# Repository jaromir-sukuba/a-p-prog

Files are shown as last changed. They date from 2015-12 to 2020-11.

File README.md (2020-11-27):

# Programmer for 8-bit PIC devices built upon AVR (or Arduino)

For [Micro progmeter](https://github.com/jaromir-sukuba/micro_progmeter) project I want to deliver full set of open-source materials, but it would be shame if folks trying to replicate the project would have to buy another programmer to flash the PIC MCU, so I decided to do a little bit of brain stretching and implement PIC16F1xxx programmer with... Arduino. I really can't say I love this platform, but it is low cost and available.
Together with SDCC compiler this serves as completely open-source basis for many 8-bit PIC devices.

The current project status: Programmer working, sources need cleanup, perhaps rework of its structure (it grew out of its simple structure).
# List of supported devices is at the end of this page.

## Hardware
There are two options fo hardware for this project:

### Hardware option 1 - Arduino hardware
Take any Arduino with ATmega328P, like Uno or most of cheap chinese knock-off boards. Considering the target has its own power supply, connect GND, MCLR, PGC and PGD lines to respective pins on arduino as follows:

| Arduino pin | AVR pin | Target PIC pin | Comment |
|---|---|---|---|
| GND | GND | GND | common ground |
| 5V | VDD | VDD | optional*- power supply for PIC MCU, you may power target from other source |
| A3 | PC3 | MCLR | reset line of PIC MCU |
| A1 | PC1 | PGD | programming data line |
| A0 | PC0 | PGC | programming clock line |

* If you are powering target PIC from other power source (in circuit programming), series resistors (something like 470-1000 Ohms) in MCLR, PGC and PGD lines are good idea, it will somehow decrease currents flowing through IO pins due to power supplies differences between arduino and target board. In this configuration, even targets running at 3,3V are possible to program, though it is dirty practice.

Power it up, no smoke should be released. Run arduino IDE, open programmer firmware from here (/fw/pp.ino), complie and upload to arduino board - now you have PIC programmer ready to go. Go to software below.

The programmer is proven to work with some generic Uno board from china, as well as chinese arduino-nano clone


### Hardware option 2 - dedicated board
I designed this little board, see at /hw directory

Considering the target has its own power supply, connect GND, MCLR, PGC and PGD lines to respective pins on PIC programmer (notice the pinout similar to PICkit programmers). Vdd line is not currently used ad it is not needed for operation of programmer, but future revisions of firmware may take advantage of this pin and detect target VDD.
The hardware works with both FT232RL and CY7C65213 in place of USB/serial converter. Both were proven to work, with no other hardware difference.


Use [another arduino](https://www.arduino.cc/en/Tutorial/ArduinoISP) (or proper ISP programmer) to load Arduino UNO bootloader to PIC programmer board (performed only once), turning it into regular arduino compatible board.



Ensure JP2 is closed, then you can load new firmware into PIC programmer using regular Arduino IDE. Open jumper JP2. Now you have your programmer ready to go, move on to software.
The firmware should be able to compile outside Arduino IDE as it doesn't contain any Arduino-specific stuff, though I haven't tried that.

## Software

When running under Linux, download source from this repository and run

`gcc -Wall pp3.c -o pp3`

This should build executable pp3. When working under windows, you can download compiled binary from this repository. Alternatively, you can build it from source - install minGW and run

`gcc -Wall pp3.c -o pp3`

ie. the same procedure as on Linux. This should result in silent build with pp3.exe executable created.

Running the executable with no parameters should only bring banner "pp programmer". Though running with basic set of parameters

`./pp3 -c /dev/ttyACM0 -t 16f1829 file.hex`

under Linux, where -c parameter denotes port to be accessed, -t parameter defines PIC to be programmed and last parameter is hex file to be downloaded; or

`pp3.exe -c COM30 -t 16f1829 file.hex`

under Windows should program the target PIC; with expected result:

	$ ./pp3 -c /dev/ttyACM0 -t 16f1829 file.hex
    Opening serial port
    Device ID 0x27E4
    Programming FLASH (16384 B in 256 pages)
    Programming config
    Verifying FLASH (16384 B in 256 pages)
    Verifying config
    Releasing MCLR

## Notes on software

If you are running the hardware on generic arduino board or you forget to open jumper JP2 after loading firmware on dedicated hardware, you may need to insert waiting time after opening serial port and before communication - to ensure Arduino bootloader times out after opening serial port and takes control to programmer firmware. It should look like this

`pp3.exe -c COM30 -s 1700 -t 16f1829 file.bin`

where number after -s switch defines the number of miliseconds to wait after opening the serial port.

You may omit the actual programming using -p switch or verification using -n switch, when using both the programmer only checks target device signature and exits.

`$ ./pp3 -c /dev/ttyACM0 -p -n -t 16f1829 file.bin`

    Opening serial port
    Device ID 0x27E4
    Releasing MCLR

you can add some debug output info using -v parameter, ranging from -v 1 to -v 4. It may be suitable for debugging, -v 4 prints out all byte transaction on serial port, so be prepared for huge output.
There is database file pp3_devices.dat which hold information of supported PIC types. For now, the filename is fixed in code can't be changed and file has to be in the same directory as pp executable..

## Supported devices

Obviously, there is more supported than verified (tested) devices. I tried to test at least one device from specific family. The members from one family are usually very very similar, giving me enough confidence to mark them as supproted. Of course, typos can happen, but those are easy to correct.

**DEVICE**|**TESTED**
:-----:|:-----:
PIC12F1501|YES
PIC12F1571| 
PIC12F1572|YES
PIC12F1612|YES
PIC12F1822|YES
PIC12F1840|YES
PIC12LF1501|YES
PIC12LF1552|YES
PIC12LF1571| 
PIC12LF1572| 
PIC12LF1612| 
PIC12LF1822| 
PIC12LF1840|YES
PIC16F1454| 
PIC16F1455|YES
PIC16F1459| 
PIC16F1503|YES
PIC16F1507|YES
PIC16F1508| 
PIC16F1509|YES
PIC16F1512| 
PIC16F1513| 
PIC16F1516|YES
PIC16F1517| 
PIC16F1518| 
PIC16F1519| 
PIC16F1528| 
PIC16F1529| 
PIC16F15313| 
PIC16F15323| 
PIC16F15324| 
PIC16F15325| 
PIC16F15344| 
PIC16F15345| 
PIC16F15354| 
PIC16F15355|YES
PIC16F15356| 
PIC16F15375| 
PIC16F15376| 
PIC16F15385| 
PIC16F15386| 
PIC16F1574| 
PIC16F1575|YES
PIC16F1578| 
PIC16F1579| 
PIC16F1613|YES
PIC16F1614| 
PIC16F1615|YES
PIC16F1618| 
PIC16F1619|YES
PIC16F1703|YES
PIC16F1704| 
PIC16F1705| 
PIC16F1707| 
PIC16F1708| 
PIC16F1709| 
PIC16F1713| 
PIC16F1716| 
PIC16F1717| 
PIC16F1718|YES
PIC16F1719| 
PIC16F1764| 
PIC16F1765|YES
PIC16F1768| 
PIC16F1769| 
PIC16F1782| 
PIC16F1783|YES
PIC16F1784| 
PIC16F1786| 
PIC16F1787| 
PIC16F1788|YES
PIC16F1789| 
PIC16F1824| 
PIC16F1825| 
PIC16F1826| 
PIC16F1827| 
PIC16F1828| 
PIC16F1829|YES
PIC16F18313| 
PIC16F18323| 
PIC16F18324| 
PIC16F18325| 
PIC16F18326| 
PIC16F18344| 
PIC16F18345| 
PIC16F18346|YES
PIC16F18424| 
PIC16F18425| 
PIC16F18426| 
PIC16F18444| 
PIC16F18445| 
PIC16F18446| 
PIC16F18455| 
PIC16F18456| 
PIC16F1847| 
PIC16F18854| 
PIC16F18855|YES
PIC16F18856| 
PIC16F18857| 
PIC16F18875|YES
PIC16F18876| 
PIC16F18877| 
PIC16F19155| 
PIC16F19156|YES
PIC16F19175| 
PIC16F19176|YES
PIC16F19185| 
PIC16F19186| 
PIC16F19195| 
PIC16F19196| 
PIC16F19197| 
PIC16F1933|YES
PIC16F1934| 
PIC16F1936| 
PIC16F1937| 
PIC16F1938| 
PIC16F1939| 
PIC16F1946| 
PIC16F1947| 
PIC16LF1454| 
PIC16LF1455|YES
PIC16LF1459| 
PIC16LF1503|YES
PIC16LF1507| 
PIC16LF1508|YES
PIC16LF1509| 
PIC16LF1512| 
PIC16LF1513| 
PIC16LF1516| 
PIC16LF1517| 
PIC16LF1518| 
PIC16LF1519| 
PIC16LF1528| 
PIC16LF1529| 
PIC16LF15313| 
PIC16LF15323| 
PIC16LF15324| 
PIC16LF15325| 
PIC16LF15344| 
PIC16LF15345| 
PIC16LF15354| 
PIC16LF15355| 
PIC16LF15356| 
PIC16LF15375| 
PIC16LF15376| 
PIC16LF15385| 
PIC16LF15386| 
PIC16LF1574| 
PIC16LF1575| 
PIC16LF1578| 
PIC16LF1579| 
PIC16LF1613| 
PIC16LF1614| 
PIC16LF1615| 
PIC16LF1618| 
PIC16LF1619|
PIC16LF1703| 
PIC16LF1704|YES
PIC16LF1705| 
PIC16LF1707| 
PIC16LF1708| 
PIC16LF1709| 
PIC16LF1713|YES
PIC16LF1716| 
PIC16LF1717| 
PIC16LF1718| 
PIC16LF1719| 
PIC16LF1764| 
PIC16LF1765| 
PIC16LF1768| 
PIC16LF1769| 
PIC16LF1782| 
PIC16LF1783| 
PIC16LF1784| 
PIC16LF1786| 
PIC16LF1787| 
PIC16LF1788| 
PIC16LF1789| 
PIC16LF1824| 
PIC16LF1825| 
PIC16LF1826| 
PIC16LF1827| 
PIC16LF1828| 
PIC16LF1829|YES
PIC16LF18313| 
PIC16LF18323| 
PIC16LF18324| 
PIC16LF18325| 
PIC16LF18326| 
PIC16LF18344| 
PIC16LF18345| 
PIC16LF18346| 
PIC16LF18424| 
PIC16LF18425| 
PIC16LF18444| 
PIC16LF18445| 
PIC16LF18455| 
PIC16LF18456| 
PIC16LF1847| 
PIC16LF18854| 
PIC16LF18855| 
PIC16LF18856| 
PIC16LF18857| 
PIC16LF18875| 
PIC16LF18876| 
PIC16LF18877| 
PIC16LF1902| 
PIC16LF1903|YES
PIC16LF1904| 
PIC16LF1906| 
PIC16LF1907| 
PIC16LF19155| 
PIC16LF19156| 
PIC16LF19175| 
PIC16LF19176| 
PIC16LF19185| 
PIC16LF19186| 
PIC16LF19195| 
PIC16LF19196| 
PIC16LF19197| 
PIC16LF1933| 
PIC16LF1934| 
PIC16LF1936| 
PIC16LF1937| 
PIC16LF1938| 
PIC16LF1939| 
PIC16LF1946| 
PIC16LF1947| 
PIC18F23K22| 
PIC18F24J10|YES
PIC18F24J11| 
PIC18F24J50|YES
PIC18F24K22|YES
PIC18F24K40| 
PIC18F24K42| 
PIC18F24K50| 
PIC18F25J10| 
PIC18F25J11| 
PIC18F25J50| 
PIC18F25K22| 
PIC18F25K40| 
PIC18F25K42| 
PIC18F25K50|YES
PIC18F25K80|YES
PIC18F25Q10|YES
PIC18F26J11|YES
PIC18F26J13| 
PIC18F26J50|YES
PIC18F26J53| 
PIC18F26K22|YES
PIC18F26K40| 
PIC18F26K42| 
PIC18F26K50| 
PIC18F26K80| 
PIC18F26Q10| 
PIC18F27J13| 
PIC18F27J53|YES
PIC18F27K40| 
PIC18F27K42| 
PIC18F27Q10| 
PIC18F43K22| 
PIC18F44J10| 
PIC18F44J11| 
PIC18F44J50| 
PIC18F44K22| 
PIC18F45J10|YES
PIC18F45J11| 
PIC18F45J50| 
PIC18F45K22| 
PIC18F45K40| 
PIC18F45K42| 
PIC18F45K50| 
PIC18F45K80| 
PIC18F45Q10| 
PIC18F46J11| 
PIC18F46J13| 
PIC18F46J50| 
PIC18F46J53| 
PIC18F46K22| 
PIC18F46K40| 
PIC18F46K42| 
PIC18F46K50| 
PIC18F46K80| 
PIC18F46Q10| 
PIC18F47J13| 
PIC18F47J53| 
PIC18F47K40|YES
PIC18F47K42| 
PIC18F47Q10| 
PIC18F55K42| 
PIC18F56K42| 
PIC18F57K42|YES
PIC18F63J11| 
PIC18F63J90| 
PIC18F64J11| 
PIC18F64J90| 
PIC18F65J10| 
PIC18F65J11| 
PIC18F65J15| 
PIC18F65J50| 
PIC18F65J90| 
PIC18F65J94| 
PIC18F65K22| 
PIC18F65K40| 
PIC18F65K80| 
PIC18F65K90| 
PIC18F66J10| 
PIC18F66J11| 
PIC18F66J15|YES
PIC18F66J16| 
PIC18F66J50| 
PIC18F66J55| 
PIC18F66J60| 
PIC18F66J65| 
PIC18F66J90| 
PIC18F66J93| 
PIC18F66J94| 
PIC18F66J99| 
PIC18F66K22| 
PIC18F66K40| 
PIC18F66K80| 
PIC18F66K90| 
PIC18F67J10| 
PIC18F67J11| 
PIC18F67J50|YES
PIC18F67J60| 
PIC18F67J90| 
PIC18F67J93| 
PIC18F67J94| 
PIC18F67K22|YES
PIC18F67K40| 
PIC18F67K90| 
PIC18F83J11| 
PIC18F83J90| 
PIC18F84J11| 
PIC18F84J90| 
PIC18F85J10| 
PIC18F85J11| 
PIC18F85J15| 
PIC18F85J50| 
PIC18F85J90| 
PIC18F85J94| 
PIC18F85K22| 
PIC18F85K90| 
PIC18F86J10| 
PIC18F86J11| 
PIC18F86J15| 
PIC18F86J16| 
PIC18F86J50| 
PIC18F86J55| 
PIC18F86J60| 
PIC18F86J65| 
PIC18F86J72| 
PIC18F86J90| 
PIC18F86J93| 
PIC18F86J94| 
PIC18F86J99| 
PIC18F86K22| 
PIC18F86K90| 
PIC18F87J10| 
PIC18F87J11| 
PIC18F87J50| 
PIC18F87J60| 
PIC18F87J72| 
PIC18F87J90| 
PIC18F87J93| 
PIC18F87J94| 
PIC18F87K22| 
PIC18F87K90| 
PIC18F95J94| 
PIC18F96J60| 
PIC18F96J65| 
PIC18F96J94| 
PIC18F96J99| 
PIC18F97J60| 
PIC18F97J94| 
PIC18LF23K22| 
PIC18LF24J10| 
PIC18LF24J11| 
PIC18LF24J50| 
PIC18LF24K22| 
PIC18LF24K40| 
PIC18LF24K42| 
PIC18LF24K50|YES
PIC18LF25J10| 
PIC18LF25J11| 
PIC18LF25J50| 
PIC18LF25K22|YES
PIC18LF25K40| 
PIC18LF25K42| 
PIC18LF25K50|YES
PIC18LF25K80| 
PIC18LF26J11| 
PIC18LF26J13| 
PIC18LF26J50| 
PIC18LF26J53| 
PIC18LF26K22| 
PIC18LF26K40| 
PIC18LF26K42| 
PIC18LF26K50| 
PIC18LF26K80| 
PIC18LF27J13| 
PIC18LF27J53| 
PIC18LF27K40| 
PIC18LF27K42| 
PIC18LF43K22| 
PIC18LF44J10| 
PIC18LF44J11| 
PIC18LF44J50| 
PIC18LF44K22| 
PIC18LF45J10| 
PIC18LF45J11| 
PIC18LF45J50| 
PIC18LF45K22| 
PIC18LF45K40| 
PIC18LF45K42| 
PIC18LF45K50| 
PIC18LF45K80| 
PIC18LF46J11| 
PIC18LF46J13| 
PIC18LF46J50| 
PIC18LF46J53| 
PIC18LF46K22| 
PIC18LF46K40| 
PIC18LF46K42| 
PIC18LF46K50| 
PIC18LF46K80| 
PIC18LF47J13| 
PIC18LF47J53| 
PIC18LF47K40| 
PIC18LF47K42| 
PIC18LF55K42| 
PIC18LF56K42| 
PIC18LF57K42| 
PIC18LF65K40| 
PIC18LF65K80| 
PIC18LF66K40| 
PIC18LF66K80| 
PIC18LF67K40| 

The whole project is licensed under MIT license, see LICENSE.md file.
Some more details to be found here https://hackaday.io/project/8559-pic16f1xxx-arduino-based-programmer

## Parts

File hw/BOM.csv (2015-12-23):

Qty | Value | Device | Package | Parts | Description | PROD_ID | VALUE
1 |  | JP1E | JP1 | JP2 | JUMPER
2 |  | LEDCHIPLED_0805 | CHIPLED_0805 | LED1; LED2 | LED
1 |  | PINHD-1X5/90 | 1X05/90 | JP1 | PIN HEADER
2 | 10k | R_0805 | R0805 | R3; R6
1 | 16MHz | CRYSTALHC49S | HC49/S | Q1 | CRYSTAL
4 | 1u | C_0806 | R0805 | C1; C2; C3; C4
2 | 22p | C_0806 | R0805 | C5; C6
6 | 470 | R_0805 | R0805 | R1; R2; R4; R5; R7; R8
1 | ATMEGA328P | ATMEGA328_SMT | TQFP32-08 | U1 | 32-Pin Atmega328 part | IC-09069 | ATMEGA328P
1 | AVR_SPI_PRG_6NS | AVR_SPI_PRG_6NS | 2X3-NS | J | AVR ISP 6 Pin
1 | FT232RL | FT232RLSSOP | SSOP28DB | IC1 | USB UART
1 | USB-MICROB | USB-MICROB | USB-MICROB | X1 | USB Connectors

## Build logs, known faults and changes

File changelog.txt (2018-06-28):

2015-12-23
- version 0.0
- PIC16F1829, PIC16F1825, PIC16LF1829 and PIC16LF1825 supported

2016-01-18
- version 0.0
- 16F1507, 1508 and LF variants added

2016-04-01
- version 0.0
- 18F25K50 added
- hex file support

2016-07-26
- version 0.0
- PIC18 bugs fixed
- 12F1571, 1572 and its LF variants added

2016-07-29
- version 0.0
- a lot of devices added and tested, 42 devices in total supported

2016-07-30
- version 0.0
- PIC12F18xx fixed
- a fex PIC16F devices tested

2016-08-05
- version 0.0
- PIC16F1619 and 1579 families added
- 68 devices supported

2016-08-16
- version 0.0
- 16F151x, 16F178x, 16F19xx families added
- PIC18FxxJxx family added
- 131 devices supported

2016-09-05
- version 0.9 (finally some sensible release number, 1.0 release is near)
- a lot of PIC18FxxJxx devices added
- bugfixes around serial port, hex file parsing and PIC18FxxKxx support
- PIC type in command line is now case insensitive
- 175 devices supported

2016-09-06
- version 0.91 (previous should be 0.90, then)
- improved programming speed, especially at windows (improved serial port handling)
- some more intelligence in PIC16 programming, results in faster programming
- PIC16F17xx devices added, 205 devices supported now

2016-09-07
- version 0.92
- major rewrite of MCU selection routines: instead of hardcoded if-then behemoth, 
there is external database parser, all MCU parameter are here in plain text
- source code shrinked from 2700 lines to 900
- source code slightly cleaned up and formatted
- added 67 new devices from PIC18FxxJxx family and one PIC16, resulting in 273 total

2016-09-12
- version 0.93
- fixed bugs for some older 18FxxJxx devices
- more devices tested

2016-09-14
- version 0.94
- added support for 12 new devices from PIC18FxxK80 family, 285 in total
- PIC18F25K80 tested
- some bugfixes

2016-09-16
- version 0.95
- added support for some PIC18FxxK22 and PIC18FxxK50 devcies, 305 in total
- there is not much LVP ICSP-able 8-bit PIC devcies left
- some more devices tested, 47 in total

2018-06-17
- after a long hiatus, version 0.96
- implemented newly introduced programming algorithm for PIC16F1xxxx devices
- hopefully nothing old broken
- 14 new devices, resulting in 319 total
- some new devcies still missing

2018-06-18
- vresion 0.97
- some PIC16F devices are somehow faster to program
- new devices added PIC16F183xx, PIC16F185xx, PIC16F19xxx), 379 in total

2018-06-19
- version 0.98
- PIC16F184xx, PIC18FxxK40 and PIC18Fxx42 added, now 433 devices in total
- minor programming speed increase

2018-06-28
- version 0.99
- PIC18FxxQ10 support added, now 439 devices in total

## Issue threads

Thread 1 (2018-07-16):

Need help to use this to update PIC18F57K42

ashasingh2018, 2018-07-16:
Hi,
My system consists of a 4Duino (has ATmega32U4, AVR) and PIC18F57K42.  The
4Duino talks to the PIC via I2C.
The 4Duino has a USB interface that can talk to the PC

I use Arduino IDE to build the 4Duino code and flash the 4Duino.
I use a JTAG programmer to flash the PIC code (uses ICD 3 and MPLAB v4.15). But to do this we have to open the encasing to get to the JTAG pins which is why we want to be able to do the PIC firmware upgrade without opening the encasing.

I looked at your programming tool here and I was wondering if I would be able to use it.
Can I use the 4Duino with your pp.ino to program the pic ?

I tried to build pp.ino using the IDE but it failed because of the macros  below -- it cannot find these.
     UBRR0H = ((_UBRR) & 0xF00);
    UBRR0L = (uint8_t) ((_UBRR) & 0xFF);
     UCSR0B |= _BV(TXEN0);
     UCSR0B |= _BV(RXEN0);

Any help and suggestion would be appreciated very much. Thanks, Asha

jaromir-sukuba, 2019-01-11:
The firmware is using Atmega328 specific IO access. It can be probably ported to USB based devices, but it will not be trivial and I'm not planning to do this in near future.
For now I'm closing this issue.

Closed 2019-01-11.

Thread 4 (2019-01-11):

Config errors?

martiinezz, 2019-01-11:
PP programmer, version 0.99
Sleeping for 1700 ms while arduino bootloader expires
Device ID: 2760
Programming FLASH (16384 B in 256 pages)
Programming config
Verifying FLASH (16384 B in 256 pages)
Verifying config
config 2 error: E:0x3EFF R:0x1EFF

Can you tell me why I do get this errors? It seems like PIC is not being programmed correctly. Works but not in full. Any ideas how to fix this?

jaromir-sukuba, 2019-01-11:
Could you, please share the hex file you are programming and command line you are using to run the programmer software, so I can reproduce the error?

martiinezz, 2019-01-11:
Doing this on Linux (Mint 18.3) with command:
pp3 -c /dev/ttyUSB0 -s 1700 -t 16f1825 simple-basic.hex

[hex.zip](https://github.com/jaromir-sukuba/a-p-prog/files/2749771/hex.zip)

Both files give the same errors.

The source code comes from here:

https://github.com/kortas87/simple-evse/tree/master/simple-evse.X

martiinezz, 2019-01-18:
Any hints what's wrong?

martiinezz, 2019-02-01:
Compilation summary:

Memory Summary:
    Program space        used   39Bh (   923) of  2000h words   ( 11.3%)
    Data space           used    38h (    56) of   400h bytes   (  5.5%)
    EEPROM space         used     0h (     0) of   100h bytes   (  0.0%)
    Data stack space     used     0h (     0) of   3C8h bytes   (  0.0%)
    Configuration bits   used     2h (     2) of     2h words   (100.0%)
    ID Location space    used     0h (     0) of     4h bytes   (  0.0%)

I think the problem is with Configuration bits - everything else seems to work just fine.

delight-f, 2021-09-30:
Same error for me!!

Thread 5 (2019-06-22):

Programming PIC18F14K50

matangk, 2019-06-22:
Great work so far!
Any reason it wont work with PIC18F14K50?
Its not on the supported device list..
Cheers!

jaromir-sukuba, 2020-11-27:
This one requires either high voltage on MCLR or wiggling with PGM pin, that is older variant of low voltage programming.
I decided to support only newer low voltage programming PIC types (starting ~ 10 years ago), so 14K50 will not be supported any time soon.

Closed 2020-11-27.

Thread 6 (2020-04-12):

How can I figure out theMK preferences?

vporoshok, 2020-04-12:
Hi! I have a circuit based on PIC16F84A. I've tried this project to upload the hex file on it, but there is no this MK in the database. I've found flash size from data sheets, but how can I get other options: page size, id, and mask?

jaromir-sukuba, 2020-04-12:
PIC16F84A can't be programmed using the hardware, as PIC16F84A doesn't support low voltage programming (LVP) and therefore isn't supported in software too.

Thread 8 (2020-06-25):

PIC24FJ

fabioriksilva, 2020-06-25:
Is it possible make some changes in this project to add 24FJ(16bit) processors?
  Today, I'm using ARM in 90% of my projects, cause of that I have made a pattern writer in all my projects using the DAPlink project as: https://github.com/ARMmbed/DAPLink.

   This project has an usart CDC implemented, that runs very well.

    So, I would like tho know if you can helping me to put up the model:
    PIC24FJ128GC010
    https://www.microchip.com/wwwproducts/en/PIC24FJ128GC010

    I really would appreciate your help, as I just starting with github projects.

   Thank you so much!

jaromir-sukuba, 2020-06-26:
Hello,
from technical point of view, there is nothing stopping from adding 16-bit MCU support and at some point in the project I thought of adding it, however I decided no to do it, because:
1, Programmer is slow (theoretical limit is 5kB/s, however it's less in practice due to simple buffering). 8-bitters do usually have less of FLASH than 16-bit ones, so this slow-ness isn't that much of a problem.
2, There isn't open source compiler for 16-bit PICs. This simple open-source programmer is good match to SDCC.
Users using XC16 can also use rest of Microchip's ecosystem with their programmers, being MUCH faster than this arduino based one.
3, It's quite bit of work and adding it into my spaghetti code wouldn't be pleasing experience.

The programmer software and firmware would need at least major rewrite in order to become half-usable 16-bit PIC programmer. Ideally, hardware rework would be advisable, because this started as one-off quick project and grown much out of original scope.
So, for now the answer is no, but I'm open to pull requests.

Closed 2020-07-02.

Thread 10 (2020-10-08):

facing problem while flashing PIC16F18875

embhobbb, 2020-10-08:
i am using your programmer to flash PIC16F18875 but i am getting error as follows.
```
E:\DIY\Programmer\PIC Programmer using Arduino\picProg\sw>pp3.exe -c COM4 -s 1700 -t 16f18875 PwmGen.X.production.hex
PP programmer, version 0.99
Sleeping for 1700 ms while arduino bootloader expires
Wrong device ID: 0000, expected: 306d
Check for connection to target MCU, exiting now
```

I could able to flash other controller PIC16F1847 but not this one.
PIC16F18875 has MCLR resistor of 10K connected and pulled up to VDD. other than this i have not connected anything.

embhobbb, 2020-10-08:
```
pp3.exe -c COM4 -s 1700 -t 16f18875 PwmGen.X.production.hex
PP programmer, version 0.99
Sleeping for 1700 ms while arduino bootloader expires
Wrong device ID: 0000, expected: 306d
Check for connection to target MCU, exiting now
```

jaromir-sukuba, 2020-11-27:
This looks like a duplicate of issue #9 , closing.

embhobbb, 2020-12-01:
Thanks for your reply. My connection is very simple which works with pickit3. But my pickit3 is not working now. I found your project very helpful. Here are the commands i was trying..
E:\DIY\Programmer\PIC Programmer using Arduino\picProg\sw>pp3.exe -c COM12  -s 1700 -t 16f18875 test.X.production.hex
PP programmer, version 0.99
Sleeping for 1700 ms while arduino bootloader expires
Device ID: 306d
Programming FLASH (16384 B in 256 pages)
Programming config
Verifying FLASH (16384 B in 256 pages)
Verifying config
Error at 0x4007 E:0x1F R:0x3F

embhobbb, 2020-12-01:
[test.X.production.txt](https://github.com/jaromir-sukuba/a-p-prog/files/5622251/test.X.production.txt)

here is the attached hex file. Please change the extention from .txt to .hex.

Closed 2020-11-27.

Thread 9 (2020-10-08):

facing problem while flashing PIC16F18875

embhobbb, 2020-10-08:
i am using your programmer to flash PIC16F18875 but i am getting error as follows.
`E:\DIY\Programmer\PIC Programmer using Arduino\picProg\sw>pp3.exe -c COM4 -s 1700 -t 16f18875 PwmGen.X.production.hex
PP programmer, version 0.99
Sleeping for 1700 ms while arduino bootloader expires
Wrong device ID: 0000, expected: 306d
Check for connection to target MCU, exiting now`

I could able to flash other controller PIC16F1847 but not this one.
PIC16F18875 has MCLR resistor of 10K connected and pulled up to VDD. other than this i have not connected anything.

jaromir-sukuba, 2020-11-27:
Could you, please, post a schematics diagram or photo of your setup?
16F18875 is among tested and proven ones; I'm not ruling out problem in my code, but I need more information to focus on the issue.

Closed 2022-03-04.

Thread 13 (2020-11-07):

Arduino Mega as the programmer (the pins are differents)

Cystor, 2020-11-07:
Hi,
I was using Arduino Mega to test this programmer and the pins are subtly differents.
I think that include the pins in your docs can help the people a lot.

Here's the complete modification i've made:
[Micro Progmeter.docx](https://github.com/jaromir-sukuba/a-p-prog/files/5504952/Micro.Progmeter.docx)

Below is the table with pins for the Arduino Mega (just for previews):

| Arduino UNO pin | Arduino MEGA pin | AVR pin | Target PIC pin |
| ------------------ | ------------------- | -------- | -------------- |
| GND                    | GND                      | GND      | GND              |
| 5V                       | 5V                         | VDD       | VDD              |
| A3                       | 34                         | PC3        | MCLR            |
| A1                       | 36                         | PC1        | PGD              |
| A0                       | 37                         | PC0        | PGC              |

Thanks.

jaromir-sukuba, 2020-11-27:
Thanks for contribution, I'll update readme document.

Closed 2020-12-02.

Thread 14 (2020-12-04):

PIC12F1840: Wrong device ID: 0000, expected: 1b80

silvioprog, 2020-12-04:
Hi.

I have been trying to use this application on Windows to program a PIC12F1840, however, the `pp3` reports the following problem:

```
C:\>pp3.exe -c COM7 -t 12f1840 blink.X.production.hex
PP programmer, version 0.99
Wrong device ID: 0000, expected: 1b80
Check for connection to target MCU, exiting now
```

My is an Arduino Uno connected as following:

| Arduino pin | Target PIC pin |
|-|-|
| GND | GND |
| 5V | VDD |
| A3 | MCLR |
| A1 | ICSPDAT |
| A0 | ICSPCLK |

Note: I'm using series resistors (470 Ohms) because the target IC is in the board below being programmed via ICSP:

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

NOTE: the board was programmed via PICKit3 before, so the problem is not related to the board.

HEX file for testing in attachment, It is just a blink application (in `RA5` pin) generated from MCC using latest XC8 version.

[teste.X.production.hex.txt](https://github.com/jaromir-sukuba/a-p-prog/files/5644539/teste.X.production.hex.txt)

TIA for any help to solve it!

1001kenny, 2021-03-23:
It could be a PIC12LF1840; I bought on aliexpress 10 mcu marked as PIC12F1840 and got PIC12LF1840 instead. I don't know if it is a fake chip remarked or if it is a mistake of microchip.
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

Lissanro, 2022-03-04:
I have the same issue. What I have is just PIC12F1840 soldered to 8-pin breakout board, and connected to Arduino Nano as silvioprog described. At first I tried to use Arduino Mega at 3.3V to program it, but had the same issue, so I thought using Arduino Nano at 5V will help, but I still get device ID "0000". Any ideas what else to try?

Lissanro, 2022-03-04:
According to the data sheet, Vpp on MCLR needs to be within 8-9V range. I found another project https://diyodemag.com/projects/arduino_pic_programmer they had to use charge pump to generate high voltage, since using 5V from Arduino is not sufficient, and adding pull-up to high voltage would kill the Arduino, so opto-isolator is necessary.

I'm not sure if reading the device ID supposed to work without 9V Vpp? If reading device ID happens after entering programming mode, then I guess it is impossible, because 12F1840 will not enter programing mode without 8-9V Vpp according to the datasheet.

Lissanro, 2022-03-04:
After reading the datasheet carefully, I see that PIC12F1840 supports Low-Voltage Programming so in theory it should work using VDD only, without high voltage. But unfortunately so far I cannot make it work. I do not have high-voltage programmer so I cannot try high-voltage programming.

jaromir-sukuba, 2022-03-04:
I personally verified PIC12F1840 and it worked. Could you show me your hardware connection?

Lissanro, 2022-03-05:
Sure, I would appreciate any ideas what could be wrong.

```
Arduino pin | PIC12F1840 pin
        GND | GND
         5V | VDD
         A3 | MCLR
         A1 | ICSPDAT
         A0 | ICSPCLK
```

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
It may be hard to see connection on the photos, especially the last one, but at very least it shows 5V (the red wire) is connected to pin 1 (VDD) and the brown wire to ping 8 (GND). Other connections are as described above, I checked them multiple times.

I also connected oscilloscope, and captured first sequence of signals after ICSPCLK was triggered for the first time. Yellow line is MCLR and for the duration of captured period it is about 0V, the green line is ICSPCLK and the red line is ICSPDAT.
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
PIC12F1840 is brand new, it was always connected with right polarity and wasn't overheated during soldering, and I checked that every wire conducts electricity as it should. From what I see in the oscilloscope, it seems to confirm I have used right Arduino pins. Unfortunately all I get is the error "Wrong device ID: 0000, expected: 1b80".

Am I doing something wrong, and if not, is it worth to try high voltage programming (I have no problem adding it in the circuit, but I did not figured out yet how to change the firmware)?

jaromir-sukuba, 2022-03-09:
Hello,
I just tried to take fresh arduino compatible board, downloaded sources from repository, flashed the arduino board, connected 12F1840 on a piece of breadboard and it just worked.
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

Are you sure the PIC is new? Does it come from reputable source?

Lissanro, 2022-03-16:
I got it from AliExpress seller, and they had a lot of good feedback, so this can be considered a reputable source. I double checked everything, and to my surprise I have discovered that ground on my soldering iron wasn't properly connected, and AC voltage was present on the soldering iron. Perhaps this is what killed it. I decided to buy one more 12F1840 locally because I couldn't wait 1-2 months again for a delivery from AliExpress, I really needed 12F1840 for an old project for which I had the source code, but porting it to modern microcontroller would take many days of work.

I of course fixed ground connection on my ESD-safe soldering iron before soldering. After that, I have soldered it and tried programming it, and it worked. I tested programming with 3.3V and 5V, in both cases programming finished successfully.

Perhaps my experience would be useful to somebody in the future (this thread comes up high in Google when searching for "Wrong device ID: 0000, expected 1b80"), but the point is, programming firmware and software works fine, my issue was because of dead 12F1840. I was not able to realise this right away because I was new to this and did not have another PIC to test at the time.

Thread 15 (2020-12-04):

[FEATURE REQUEST] Support for 12F629/12F675/12F683 and 16F628A/16F676

silvioprog, 2020-12-04:
Those devices above are very popular, so it would be nice to add support for them. 😃👍

thinhx2, 2020-12-19:
> Những thiết bị ở trên rất phổ biến, vì vậy sẽ rất tốt nếu bạn thêm hỗ trợ cho chúng. 😃👍

They use high voltage (12v) to program instead use low voltage (5v)

jaromir-sukuba, 2022-03-04:
Those MCUs don't support low voltage programming and need higher than 5V on MCLR pin to enter programming mode. Those are not and will not be supported unless hardware is modified.
What more, with the older PICs there is a lot of programming algorithm variations, complicating the work.

Closed 2022-03-04.

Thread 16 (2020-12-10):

Serial port failed to receive a byte

Alpha330i, 2020-12-10:
im trying to flash a PIC18F25k80 and always get stuck at the point, when serial port is failing to receive a byte. i connected all correct but im doing something wrong with software maybe?

C:\Users\...\sw>pp3.exe -c COM4 -s 1700 -t 18f25k80 text.hex
PP programmer, version 0.99
Sleeping for 1700 ms while arduino bootloader expires
Device ID: 6180
Programming FLASH (32768 B in 512 pages per 64 bytes):
Serial port failed to receive a byte, read returned 0
COM4: No error

jaromir-sukuba, 2020-12-15:
Well, that is weird. Are you sure you have the newest firmware?

Alpha330i, 2020-12-15:
Yes im trying with the latest firmware. Maybe its because the hex file is bigger than 32kb which Arduino is capable.
Hex File is 87kb

InputBlackBoxOutput, 2021-01-06:
I got the same error!

I am using it to program PIC18F2550.  When I got the error, I used the -v 4 to get verbose output. The output is as follows:
```text
PP programmer, version 0.99
Opening serial port
Opening filename blink.hex
File open

Read 44 chars: :100000000EEF00F00000000000EF00F00000000024
Line len 16 B, type 0, address 0x0000 offset 0x0000, EFF 0x000000
0EEF00F00000000000EF00F000000000

<More reads>

Read 12 chars: :00000001FF
Line len 0 B, type 1, address 0x0000 offset 0x0030, EFF 0x300000

Entering programming mode
TX: 0x01
TX: 0x00
RX: fail
Serial port failed to receive a byte, read returned 0
COM3: No error
```

The .hex file has a file size of 1kb

What we can deduce is that the file size is not causing the error. The error occurred when it entered the programming mode.

WydD, 2021-01-27:
Heyo, I had the same issue using a Arduino Uno and a pretty fast computer.
I figured out that if your computer sends data too fast, and because the Uno doesnt have a lot of RAM (2k) and it cant handle the buffers size.

So, I worked around the issue by adding a `Sleep(1);` in `putByte`, it may be slower but it's still a few seconds to program a 16f1455.

Thanks for this project!

Alpha330i, 2021-02-07:
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

Hello Thank you, in which line did you paste the sleep(1)?

ffpp2003, 2021-08-20:
I figured out that after the progam fails one time, the second time always works. Could it be that the problem is that there is no enough time for the serial connection to get set up, and thats why always it fails to recive the byte on the first time, and not the subsequent ones?

delight-f, 2021-09-21:
Can confirm I am getting this error too on a 16f1455.

jaromir-sukuba, 2022-03-09:
I've seen the problem (Serial port failed to receive a byte, read returned 0) on a specific computer, not on other computers I ran this software.
As a workaround I found that opening the serial port with another program - in this case serial terminal - closing and then retrying pp3 software resulted in expected operation. I'm not sure yet what's the reason behind it - probably serial port initialization or buffers flushing is not sufficient in some cases and that causes the serial port to receive garbage, on the specific computer/OS. I'll investigate this some more.

cjacker, 2022-06-17:
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

try increase sleep time like '-s 2000'?

I tested with PIC16F1823 and a China-made nano, it works with '-s 2000' without any issue.

ready4droid, 2022-07-16:
I'm getting this error on my Arduino UNO as well, didn't have any issues with my chinese clone nano, but my uno gives me the "Serial port failed to receive a byte, read returned 0".  Oddly, it does Verifying FLASH, which looks to complete, and then gives me this error after it gets to Verifying config.

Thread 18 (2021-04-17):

Exchanged Device Id between PIC18F47Q10 and PIC18F27Q10, and a modification of .ino

SuperFabius, 2021-04-17:
Hi, I've successfully used your programmer on linux (with a common Arduino UNO) to flash a PIC18F47Q10!

Please note that the Device Id of PIC18F27Q10 and PIC18F47Q10 are exchanged, so I've corrected at first them in your "pp3_devices.dat" files.

I've also noticed that  the MCLR/VPP pin (A3) is normally at HIGH level. This can be an issue when connecting your programmer to self-powerd boards. I've checked on both the MPLAB Pickit 4 and MPLAB SNAP programmers and they leave the MCLR/VPP pin at GND or 3-stated.

So I've modified your .ino and added a small switch on A2 so I can put your programmer into a "stand-by" state with all the ICSP pin at GND (or 3-stated) . This allows to connect safely the ICSP cable with an un-powered target board while the Arduino Uno is powered. Then I can power the target board and change the position of the switch to let  the programmer operate as intended.

After the programming I do in sequence: set the switch to "stand-by" again, reset the Arduino UNO, un-power the target board, disconnect the ICSP cable, and finally un-power the Arduino UNO.

Here the changed part at the beginning of you "int main" function:

.....

int main (void)
{

  pinMode(13, OUTPUT);
  pinMode(A2, INPUT_PULLUP);
  while (digitalRead(A2))
  {
    digitalWrite(13, HIGH);
    _delay_ms(200);
    digitalWrite(13, LOW);
    _delay_ms(200);
  }

.....

The blinking Led of the Arduino UNO is used to give the feedback that the programmer is in the "stand-by" state, and the connection or disconnection to/from the target board is safe.

Thanks for this beautiful programmer!

I'll use it to give a simple and cheap way to program the PIC18F47Q10 MCU used inside my 68k-MBC board.

Here a couple of images of my Arduino Uno and the "ICSP adapter boad":

https://i.postimg.cc/L4PDWjcP/20210417-155447.jpg

https://i.postimg.cc/zvTkR1C7/20210417_155718.jpg

Regards.

jaromir-sukuba, 2022-03-04:
Thank you for your contribution, I merged it.

Closed 2022-03-04.

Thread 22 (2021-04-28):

PIC12F1571 does not seem to work

coopzone-dc, 2021-04-28:
I'm trying this PIC, PIC12F1571. But just trying to read the device ID with:

./pp3 -c /dev/ttyACM0 -s 1700 -p -n -t 12f1571

returns a random value, each time the command runs you get a different value. Normally in the high 0xfxxx range. Not consistent

Derek

jaromir-sukuba, 2022-03-04:
This looks like hardware connection error, please share the connection diagram.

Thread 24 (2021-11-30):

PIC18F25K22/PIC18F87K22

LyntonDev1064, 2021-11-30:
Hi

I am trying to use your program to flash PIC18f25K22 and PIC18F87K22, but I am being unsuccessful.
I am running on Linux with Arduino Nano connected to PIC (as described in datasheet).

I am receiving error:
~pp3 -c dev/ttyUSB0 -t 18f25k22
PP programmer, version 0.99
Wrong device ID: 0000, expected: 5540
Check for connection to target MCU, exiting now

Same error is presented with PIC18F87K22

Any help will be greatly appreciated.

jaromir-sukuba, 2022-03-04:
This looks like hardware connection error. Please show how you connected it.
I personally verified PIC18F26K22, very similar to your PIC18F25K22.

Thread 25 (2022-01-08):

Flashing "LF" PIC's using 5v Vdd ?

Mutanter, 2022-01-08:
Hey there, thank you very much for the great project.

One question about this I could't get from the instructions:
Is it possible to program "LF"-PIC chips with maximum 3,6v working voltage like the normal L's (for example: 16f1619 / 16lf1619) using the 5v Vdd of the Arduino Uno, as described?

Thanks in advance

Closed 2022-01-11.

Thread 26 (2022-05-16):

ADD: Please add the option to read all pic firmware and save it to local disk

alexbladex, 2022-05-16:
ADD: Please add the option to read all pic firmware and save it to local disk

TheLizard, 2022-09-03:
I have spent some time to build this feature (for PIC16 family), however, when trying to dump 3rd party firmware, probably a fuse is set to prevent reading this content.

From the PIC16LF1936 datasheet: https://ww1.microchip.com/downloads/en/DeviceDoc/41364E.pdf
REGISTER 4-1: CONFIGURATION WORD 1 (page 62)
bit 8 CPD: Data Code Protection bit(2)
1 = Data memory code protection is disabled
0 = Data memory code protection is enabled
bit 7 CP: Code Protection bit(3)
1 = Program memory code protection is disabled
0 = Program memory code protection is enabled

Note 1: Enabling Brown-out Reset does not automatically enable Power-up Timer.
2: The entire data EEPROM will be erased when the code protection is turned off during an erase.
3: The entire program memory will be erased when the code protection is turned off.

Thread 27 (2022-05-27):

Support for PIC18-Q40/Q41 family

ffliere, 2022-05-27:
Currently, it is not possible to program pic devices from the PIC18-Q40 family, error:

> Error at 0x0000 E:0xFE R:0x00

Although the software is able to pick up the correct device ID, it fails while verifying the flash (tested with PIC18F16Q40). The memory map is different between this family and the already implemented PIC18-Q10 family. It appears to be a mix of the already implemented 18-J  and 18-Q10 families.

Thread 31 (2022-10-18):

PIC16LF1454 can be programmed

ckoever, 2022-10-18:
The PIC16LF1454 was successfully programmed with the tool using an Arduino Uno clone. With the Arduino Nano (3V3) it didn't work after several attempts.

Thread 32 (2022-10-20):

PIC18F25K80 issues

oxygen155, 2022-10-20:
hello,

I have troubles with flashing open-sourced ELM327 firmware to this chip (https://github.com/uholeschak/ediabaslib).

I have successfully connected to the chip, it showed that upload (flashing) was successful, but it has failed at verification stage - _**Error at 0x0000 E:0xFE R:0x00**_ (or something along those lines, I did not saved the output log)

Now, when I connect to it again, it only tells me: Wrong device ID: ffe0, expected: 6180.

My board did not have dedicated pins for connecting a programmer, so I had to solder thin wires to some points on the PCB.

oxygen155, 2022-11-11:
Bough a cheap PicKit 2 from eBay - that one flashed my PIC in an instant.
Problem "solved"

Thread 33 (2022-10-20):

Feature request: programming EEPROM only when CP set, CPD not set

robcazzaro, 2022-10-20:
I'm trying to revive a Dyson battery. The PIC16LF1847 inside the BMS stores a lock code in EEPROM when the cells are out of balance. Even rebalancing the cells doesn't unlock the battery unless the EEPROM content is changed.

Ordinarily, trying to write to a protected chip results in an erase of the firmware. But when only the CP bit is set, and not the CPD bit, with an old version of a Microchip utility it's possible to only write into the EEPROM leaving the firmware intact

This video shows how it's done https://youtu.be/7t9yA3_KUI0?t=105

I'd like to avoid buying a Pickit3 just for this, and was hoping to use your code. Do you have any idea on how to achieve this? I'm not familiar with the PIC family, but I have extensive microprocessor experience and all the necessary tools to play with your code and submit a patch if you could help point me in the right direction (for example, by describing at a high level what needs to happen)

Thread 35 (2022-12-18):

New un-programmed 12f1840 not working (w. logic analyzer shots)

kpishere, 2022-12-18:
Hi, trying to program a 12f1840 and it does not appear to be working.

Here are some shots with the logic analyzer .. see anything wrong?  Any tips on setting decoding?

The command line response looks like this:

```
Mac-mini:a-p-prog$ sw/pp3 -c /dev/cu.usbmodem14201 -t 12f1840 dist/default/production/blinkled.X.production.hex
PP programmer, version 0.99
Device ID: 0000
Floating point exception: 8
```

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

kpishere, 2022-12-18:
ticket #14 shows a similar bit pattern as shown here but no time scale.  Looking at Uno to Pro Micro, it appears the Pro Micro is double the speed.  Clock tick above is about 260 ns. So, I've slowed it down to about 510 ns.

Still though, no joy ... yet.

kpishere, 2022-12-18:
I dunno, followed through beginning to end, it all looks as intended until it reads the device ID.

The timing looks as you see below where it tries to read the program ID twice.

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

kpishere, 2022-12-19:
Ok, so that _MSR line looks like it has some contention or something.  checked datasheet and it says to put a 230 ohm resistor between VPP (_MSR) and the programmer ... so I've added a 330 ohm (is what I had handy, close enough), and that ringing 10 ns artifact appears to be gone now.

Still, no joy though.
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

kpishere, 2022-12-19:
Ok, found the datasheet for programming this class of chip.  [programming details](http://ww1.microchip.com/downloads/en/DeviceDoc/40001720C.pdf)

Reviewed and tweaked timings which worked well enough before but weren't quite to spec.

Still though, I get this nonsense response from chip where data line almost follows the clock line.
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

kpishere, 2022-12-19:
This is very curious.  I put a pull down resistor (3.3K) on the data line.  (I tried pull up too but the level stayed high all time that it was in Input mode by he Pro Micro.)

Not how it is supposed to work.  I'll try another chip.

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

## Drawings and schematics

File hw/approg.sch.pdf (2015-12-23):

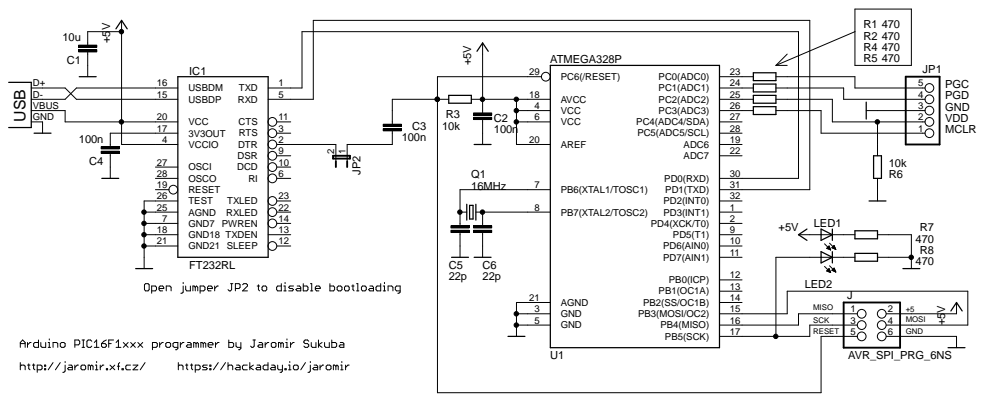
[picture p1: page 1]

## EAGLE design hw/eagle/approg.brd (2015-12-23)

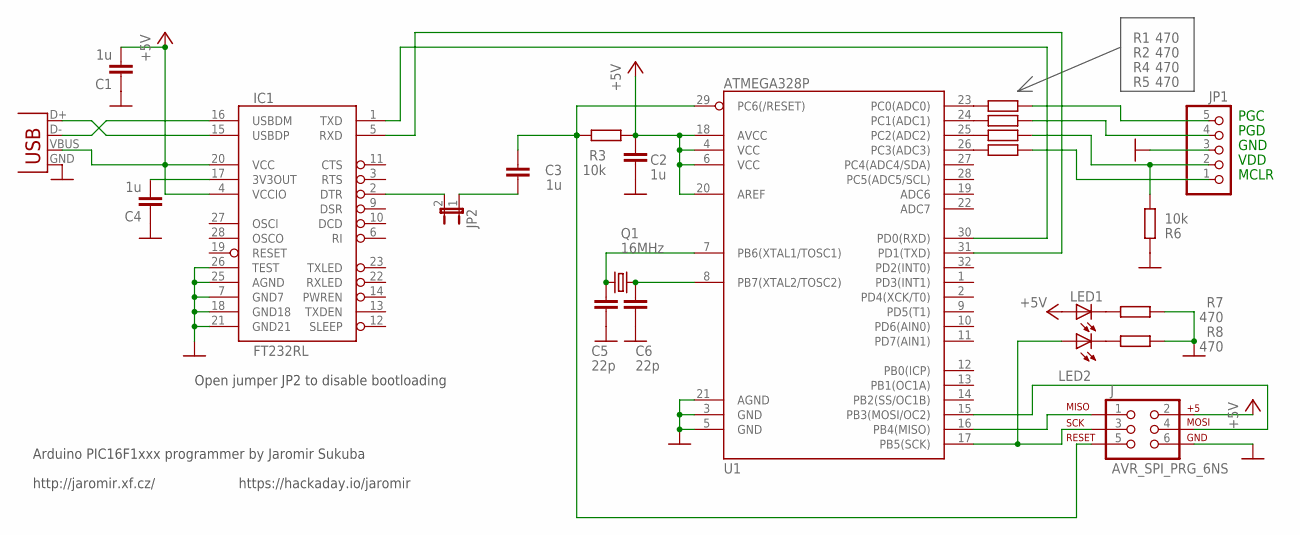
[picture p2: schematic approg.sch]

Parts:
C1, C2, C3, C4: 1u; R0805
C5, C6: 22p; R0805
IC1: FT232RL; SSOP28DB
J: AVR_SPI_PRG_6NS; 2X3-NS
JP1: PINHD-1X5/90; 1X05/90
JP2: JP1E; JP1
LED1, LED2: LEDCHIPLED_0805; CHIPLED_0805
Q1: 16MHz; HC49/S
R1, R2, R4, R5, R7, R8: 470; R0805
R3, R6: 10k; R0805
U1: ATMEGA328P; TQFP32-08
X1: USB-MICROB

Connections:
3V3: C4.2, IC1.17 (3V3OUT)
+5V: C1.2, C2.1, IC1.4 (VCCIO), IC1.20 (VCC), J.2, LED1.A, R3.1, U1.4 (VCC), U1.6 (VCC), U1.18 (AVCC), U1.20 (AREF), X1.VBUS
GND: C1.1, C2.2, C4.1, C5.2, C6.2, IC1.7 (GND7), IC1.18 (GND18), IC1.21 (GND21), IC1.25 (AGND), IC1.26 (TEST), J.6, JP1.3, R6.2, R7.1, R8.1, U1.3 (GND), U1.5 (GND), U1.21 (AGND), X1.GND
unnamed: IC1.2 (DTR), JP2.2
unnamed: C5.1, Q1.1, U1.7 (PB6(XTAL1/TOSC1))
unnamed: C6.1, Q1.2, U1.8 (PB7(XTAL2/TOSC2))
unnamed: C3.2, JP2.1
unnamed: C3.1, J.5, R3.2, U1.29 (PC6(/RESET))
unnamed: JP1.1, R5.1
unnamed: IC1.16 (USBDM), X1.D-
unnamed: J.1, U1.16 (PB4(MISO))
unnamed: J.4, U1.15 (PB3(MOSI/OC2))
unnamed: LED2.C, R8.2
unnamed: LED1.C, R7.2
unnamed: J.3, LED2.A, U1.17 (PB5(SCK))
unnamed: JP1.5, R1.1
unnamed: JP1.4, R2.1
unnamed: JP1.2, R4.1, R6.1
unnamed: R1.2, U1.23 (PC0(ADC0))
unnamed: R2.2, U1.24 (PC1(ADC1))
unnamed: R4.2, U1.25 (PC2(ADC2))
unnamed: R5.2, U1.26 (PC3(ADC3))
unnamed: IC1.15 (USBDP), X1.D+
U_RX: IC1.5 (RXD), U1.31 (PD1(TXD))
U_TX: IC1.1 (TXD), U1.30 (PD0(RXD))

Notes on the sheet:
MCLR
VDD
GND
PGD
PGC
Open jumper JP2 to disable bootloading
Arduino PIC16F1xxx programmer by Jaromir Sukuba
http://jaromir.xf.cz/
https://hackaday.io/jaromir

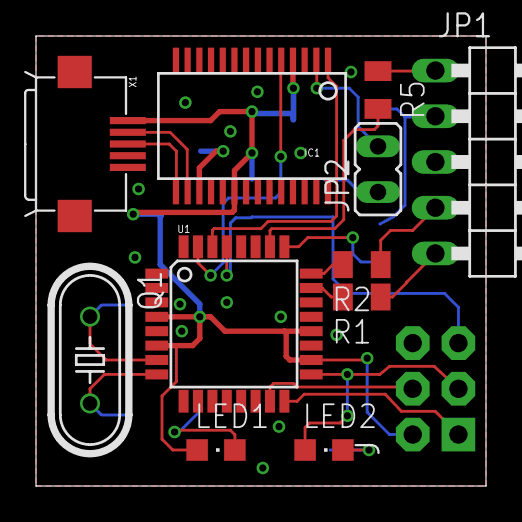
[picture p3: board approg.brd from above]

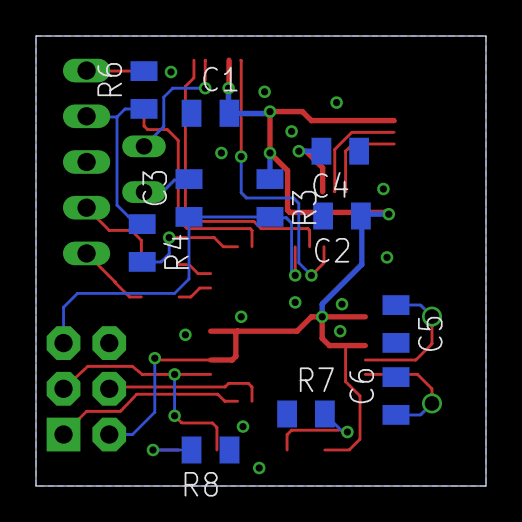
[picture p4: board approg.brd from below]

Board: 2 copper layers, 25.0 x 25.0 mm, 23 parts (11 on the bottom side), 25 nets.

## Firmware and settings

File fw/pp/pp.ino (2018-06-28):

/*
 * pp programmer, for SW 0.99 and higher
 * 
 * 
 */


#include <avr/io.h>
#include <util/delay.h>

#define ISP_PORT  PORTC
#define ISP_DDR   DDRC
#define ISP_PIN   PINC
#define ISP_MCLR  3
#define ISP_DAT   1
#define ISP_CLK   0

#define  ISP_MCLR_1 ISP_PORT |= (1<<ISP_MCLR);
#define  ISP_MCLR_0 ISP_PORT &= ~(1<<ISP_MCLR);
#define  ISP_MCLR_D_I ISP_DDR &= ~(1<<ISP_MCLR);
#define  ISP_MCLR_D_0 ISP_DDR |= (1<<ISP_MCLR);

#define  ISP_DAT_1 ISP_PORT |= (1<<ISP_DAT);
#define  ISP_DAT_0 ISP_PORT &= ~(1<<ISP_DAT);
#define  ISP_DAT_V (ISP_PIN&(1<<ISP_DAT))
#define  ISP_DAT_D_I ISP_DDR &= ~(1<<ISP_DAT);
#define  ISP_DAT_D_0 ISP_DDR |= (1<<ISP_DAT);

#define  ISP_CLK_1 ISP_PORT |= (1<<ISP_CLK);
#define  ISP_CLK_0 ISP_PORT &= ~(1<<ISP_CLK);
#define  ISP_CLK_D_I ISP_DDR &= ~(1<<ISP_CLK);
#define  ISP_CLK_D_0 ISP_DDR |= (1<<ISP_CLK);

#define  ISP_CLK_DELAY  1
void isp_send (unsigned int data, unsigned char n);
unsigned int isp_read_16 (void);
unsigned char enter_progmode (void);
unsigned char exit_progmode (void);
void isp_read_pgm (unsigned int * data, unsigned char n);
void isp_write_pgm (unsigned int * data, unsigned char n);
void isp_mass_erase (void);
void isp_reset_pointer (void);
void isp_send_8_msb (unsigned char data);
unsigned int isp_read_8_msb (void);
unsigned int isp_read_16_msb (void);
unsigned char p16c_enter_progmode (void);
void p16c_set_pc (unsigned long pc);
void p16c_bulk_erase (void);
void p16c_load_nvm (unsigned char inc, unsigned int data);
unsigned int p16c_read_data_nvm (unsigned char inc);
void p16c_begin_prog (unsigned char cfg_bit);
void p16c_isp_write_cfg (unsigned int data, unsigned int addr);
void p18q_isp_write_pgm (unsigned int * data, unsigned long addr, unsigned char n);
void p18q_isp_write_cfg (unsigned int data, unsigned long addr);

unsigned char p18_enter_progmode (void);
unsigned int p18_get_ID (void);
void p18_send_cmd_payload (unsigned char cmd, unsigned int payload);
unsigned int p18_get_cmd_payload (unsigned char cmd);
unsigned int isp_read_8 (void);
void p18_set_tblptr (unsigned long val);
unsigned char p18_read_pgm_byte (void);
void p_18_modfied_nop (void);
void p18_isp_mass_erase (void);
void p18fk_isp_mass_erase (unsigned char data1, unsigned char data2, unsigned char data3);


void usart_tx_b(uint8_t data);
uint8_t usart_rx_rdy(void);
uint8_t usart_rx_b(void);
void usart_tx_s(uint8_t * data);

#define _BAUD	57600	// Baud rate (9600 is default)
#define _UBRR	(F_CPU/16)/_BAUD - 1	// Used for UBRRL and UBRRH 


unsigned int fmimg[32] = {
                            0x1234,0x1234,0x1234,0x1234,
                            0x1234,0x1234,0x1234,0x1234,
                            0x1234,0x1234,0x1234,0x1234,
                            0x1234,0x1234,0x1234,0x1234,
                            0x1234,0x1234,0x1234,0x1234,
                            0x1234,0x1234,0x1234,0x1234,
                            0x1234,0x1234,0x1234,0x1234,
                            0x1234,0x1234,0x1234,0x1234,
                            };



unsigned int dat;
unsigned char rx,i,main_state,bytes_to_receive,rx_state;
unsigned char rx_message[280],rx_message_ptr;
unsigned int flash_buffer[260];
unsigned int test,cfg_val;
unsigned long addr;
int main (void)
{
  UBRR0H = ((_UBRR) & 0xF00);
  UBRR0L = (uint8_t) ((_UBRR) & 0xFF); 
  UCSR0B |= _BV(TXEN0);
  UCSR0B |= _BV(RXEN0);
  
  ISP_CLK_D_0
  ISP_DAT_D_0
  ISP_DAT_0
  ISP_CLK_0
  ISP_MCLR_D_0
  ISP_MCLR_1
  rx_state = 0;
  /*
  while (1)
    {
    if (usart_rx_rdy())
      {
      rx = usart_rx_b();
      if (rx=='i')
        {
        usart_tx_b ('I');
        usart_tx_b (0x0A);
        enter_progmode();
//        test = get_ID();
        exit_progmode();
        usart_tx_hexa_16(test);
        usart_tx_b (0x0A);
        }
      if (rx=='r')
        {
        usart_tx_b ('R');
        usart_tx_b (0x0A);
        enter_progmode();
        isp_reset_pointer();
        isp_read_pgm(flash_buffer,64);
        exit_progmode();
        for (i=0;i<64;i++)
          {
          if (i%4==0) usart_tx_b (0x0A);
          usart_tx_hexa_16(flash_buffer[i]);
          }
        usart_tx_b (0x0A);
        }
      if (rx=='w')
        {
        usart_tx_b ('W');
        enter_progmode();
        isp_reset_pointer();
        isp_write_pgm(fmimg,32,0);
//        p16c_isp_write_pgm(fmimg,32,32);
        exit_progmode();
        usart_tx_b ('*');
        usart_tx_b (0x0A);
        }
      if (rx=='e')
        {
        usart_tx_b ('E');
        enter_progmode();
        isp_reset_pointer();
        isp_mass_erase();
        exit_progmode();
        usart_tx_b ('*');
        usart_tx_b (0x0A);
        }
          
      }
    
    }
    */
  while (1)
    {
    if (usart_rx_rdy())
      {
      rx = usart_rx_b();
      rx_state = rx_state_machine (rx_state,rx);
      if (rx_state==3)
        {
        if (rx_message[0]==0x01)
          {
          enter_progmode();
          usart_tx_b (0x81);
          rx_state = 0;
          }
        if (rx_message[0]==0x02)
          {
          exit_progmode();
          usart_tx_b (0x82);
          rx_state = 0;
          }
        if (rx_message[0]==0x03)
          {
          isp_reset_pointer();
          usart_tx_b (0x83);
          rx_state = 0;
          }
        if (rx_message[0]==0x04)
          {
          isp_send_config(0);
          usart_tx_b (0x84);
          rx_state = 0;
          }
        if (rx_message[0]==0x05)
          {
            for (i=0;i<rx_message[2];i++)
            {
            isp_inc_pointer();
            }
          usart_tx_b (0x85);
          rx_state = 0;
          }
        if (rx_message[0]==0x06)
          {
          usart_tx_b (0x86);
          isp_read_pgm(flash_buffer,rx_message[2]);
          for (i=0;i<rx_message[2];i++)
            {
            usart_tx_b (flash_buffer[i]&0xFF);
            usart_tx_b (flash_buffer[i]>>8);
            }
          rx_state = 0;
          }
        if (rx_message[0]==0x07)
          {
          isp_mass_erase();
          usart_tx_b (0x87);
          rx_state = 0;
          }
          
        if (rx_message[0]==0x08)
          {
          for (i=0;i<rx_message[2]/2;i++)
            {
            flash_buffer[i] = (((unsigned int)(rx_message[(2*i)+1+4]))<<8) + (((unsigned int)(rx_message[(2*i)+0+4]))<<0);
            }
          isp_write_pgm(flash_buffer,rx_message[2]/2,rx_message[3]);
          usart_tx_b (0x88);
          rx_state = 0;
          }
        if (rx_message[0]==0x09)
          {
          isp_reset_pointer_16d();
          usart_tx_b (0x89);
          rx_state = 0;
          }        
        if (rx_message[0]==0x10)
          {
          p18_enter_progmode();
          usart_tx_b (0x90);
          rx_state = 0;
          }
        if (rx_message[0]==0x11)
          {
          usart_tx_b (0x91);
          addr = (((unsigned long)(rx_message[3]))<<16) + (((unsigned long)(rx_message[4]))<<8) + (((unsigned long)(rx_message[5]))<<0);
          p_18_isp_read_pgm (flash_buffer, addr, rx_message[2]);
          for (i=0;i<rx_message[2];i++)
            {
            usart_tx_b (flash_buffer[i]&0xFF);
            usart_tx_b (flash_buffer[i]>>8);
            }
          rx_state = 0;
          }
        if (rx_message[0]==0x12)
          {
          addr = (((unsigned long)(rx_message[3]))<<16) + (((unsigned long)(rx_message[4]))<<8) + (((unsigned long)(rx_message[5]))<<0);
          for (i=0;i<rx_message[2]/2;i++)
            {
            flash_buffer[i] = (((unsigned int)(rx_message[(2*i)+1+6]))<<8) + (((unsigned int)(rx_message[(2*i)+0+6]))<<0);
            }
          p18_isp_write_pgm (flash_buffer, addr, rx_message[2]/2);
          usart_tx_b (0x92);
          rx_state = 0;
          }
        if (rx_message[0]==0x13)
          {
          p18_isp_mass_erase();
          usart_tx_b (0x93);
          rx_state = 0;
          }
        if (rx_message[0]==0x14)
          {
          addr = (((unsigned long)(rx_message[3]))<<16) + (((unsigned long)(rx_message[4]))<<8) + (((unsigned long)(rx_message[5]))<<0);
          p18_isp_write_cfg (rx_message[6],rx_message[7], addr);
          usart_tx_b (0x94);
          rx_state = 0;
          }  
        if (rx_message[0]==0x23)
          {
          p18fj_isp_mass_erase();
          usart_tx_b (0xA3);
          rx_state = 0;
          }
        if (rx_message[0]==0x30)
          {
          p18fk_isp_mass_erase (rx_message[2], rx_message[3], rx_message[4]);
          usart_tx_b (0xB0);
          rx_state = 0;
          }
        if (rx_message[0]==0x31)
          {
          addr = (((unsigned long)(rx_message[3]))<<16) + (((unsigned long)(rx_message[4]))<<8) + (((unsigned long)(rx_message[5]))<<0);
          for (i=0;i<rx_message[2]/2;i++)
            {
            flash_buffer[i] = (((unsigned int)(rx_message[(2*i)+1+6]))<<8) + (((unsigned int)(rx_message[(2*i)+0+6]))<<0);
            }
          p18fk_isp_write_pgm (flash_buffer, addr, rx_message[2]/2);
          usart_tx_b (0xB1);
          rx_state = 0;
          }
        if (rx_message[0]==0x32)
          {
          addr = (((unsigned long)(rx_message[3]))<<16) + (((unsigned long)(rx_message[4]))<<8) + (((unsigned long)(rx_message[5]))<<0);
          p18fk_isp_write_cfg (rx_message[6],rx_message[7], addr);
          usart_tx_b (0xB2);
          rx_state = 0;
          }  
        if (rx_message[0]==0x40)
          {
          p16c_enter_progmode();
          usart_tx_b (0xC0);
          rx_state = 0;   
          }      
        if (rx_message[0]==0x41)
          {
          usart_tx_b (0xC1);
          addr = (((unsigned long)(rx_message[3]))<<16) + (((unsigned long)(rx_message[4]))<<8) + (((unsigned long)(rx_message[5]))<<0);
          p16c_isp_read_pgm (flash_buffer, addr, rx_message[2]);
          for (i=0;i<rx_message[2];i++)
            {
            usart_tx_b (flash_buffer[i]&0xFF);
            usart_tx_b (flash_buffer[i]>>8);
            }
          rx_state = 0;
          }
        if (rx_message[0]==0x42)
          {
          addr = (((unsigned long)(rx_message[3]))<<16) + (((unsigned long)(rx_message[4]))<<8) + (((unsigned long)(rx_message[5]))<<0);
          for (i=0;i<rx_message[2]/2;i++)
            {
            flash_buffer[i] = (((unsigned int)(rx_message[(2*i)+1+6]))<<8) + (((unsigned int)(rx_message[(2*i)+0+6]))<<0);
            }
          p16c_isp_write_pgm (flash_buffer, addr, rx_message[2]/2);
          usart_tx_b (0xC2);
          rx_state = 0;
          }
        if (rx_message[0]==0x43)
          {
          p16c_set_pc (0x8000);
          p16c_bulk_erase ();
          usart_tx_b (0xC3);
          rx_state = 0;
          }         
        if (rx_message[0]==0x44)
          {
          addr = (((unsigned long)(rx_message[3]))<<16) + (((unsigned long)(rx_message[4]))<<8) + (((unsigned long)(rx_message[5]))<<0);
          cfg_val = rx_message[6];
          cfg_val = (cfg_val<<8) + rx_message[7];
          p16c_isp_write_cfg (cfg_val, addr);
          usart_tx_b (0xC4);
          rx_state = 0;
          }                      
        if (rx_message[0]==0x45)
          {
          addr = (((unsigned long)(rx_message[3]))<<16) + (((unsigned long)(rx_message[4]))<<8) + (((unsigned long)(rx_message[5]))<<0);
          cfg_val = rx_message[6];
          cfg_val = (cfg_val<<8) + rx_message[7];
          p18q_isp_write_cfg (cfg_val, addr);
          usart_tx_b (0xC5);
          rx_state = 0;
          } 
        if (rx_message[0]==0x46)
          {
          addr = (((unsigned long)(rx_message[3]))<<16) + (((unsigned long)(rx_message[4]))<<8) + (((unsigned long)(rx_message[5]))<<0);
          for (i=0;i<rx_message[2]/2;i++)
            {
            flash_buffer[i] = (((unsigned int)(rx_message[(2*i)+1+6]))<<8) + (((unsigned int)(rx_message[(2*i)+0+6]))<<0);
            }
          p18q_isp_write_pgm (flash_buffer, addr, rx_message[2]/2);
          usart_tx_b (0xC6);
          rx_state = 0;
          }        
        }
      }      
    }
}



unsigned char rx_state_machine (unsigned char state, unsigned char rx_char)
{
if (state==0)
  {
    rx_message_ptr = 0;
    rx_message[rx_message_ptr++] = rx_char;
    return 1;
  }
if (state==1)
  {
    bytes_to_receive = rx_char;
    rx_message[rx_message_ptr++] = rx_char;
    if (bytes_to_receive==0) return 3;
    return 2;
  }
if (state==2)
  {
    rx_message[rx_message_ptr++] = rx_char;
    bytes_to_receive--;
    if (bytes_to_receive==0) return 3;
  }
return state;  
}


void isp_read_pgm (unsigned int * data, unsigned char n)
{
unsigned char i;
//_delay_us(3*ISP_CLK_DELAY);
for (i=0;i<n;i++)  
  {
  isp_send(0x04,6);
  data[i] = isp_read_14s();
  isp_send(0x06,6);
  }
}




void isp_write_pgm (unsigned int * data, unsigned char n, unsigned char slow)
{
unsigned char i;
//_delay_us(3*ISP_CLK_DELAY);
for (i=0;i<n;i++)  
  {
  isp_send(0x02,6);
  isp_send(data[i]<<1,16);  
  if (i!=(n-1))
    isp_send(0x06,6);
  }
isp_send(0x08,6);
if (slow==1)
  _delay_ms(5);
else
  _delay_ms(3);
isp_send(0x06,6);
}

void isp_send_config (unsigned int data)
{
isp_send(0x00,6);
isp_send(data,16);
}

void isp_mass_erase (void)
{
//_delay_ms(10);
//_delay_us(3*ISP_CLK_DELAY);
//isp_send(0x11,6);
isp_send_config(0);
isp_send(0x09,6);
_delay_ms(10);
//isp_send(0x0B,6);
//_delay_ms(10);
}



void isp_reset_pointer (void)
{
//_delay_us(3*ISP_CLK_DELAY);
isp_send(0x16,6);
}

void isp_reset_pointer_16d (void)
{
//_delay_us(3*ISP_CLK_DELAY);
isp_send(0x1D,6);
isp_send(0x0,8);
isp_send(0x0,8);
isp_send(0x0,8);
}

void isp_inc_pointer (void)
{
//_delay_us(3*ISP_CLK_DELAY);
isp_send(0x06,6);
}


unsigned int isp_read_16 (void)
{
unsigned char i;
unsigned int out;
out = 0;
ISP_DAT_D_I
//_delay_us(3*ISP_CLK_DELAY);
for (i=0;i<16;i++)
  {
  ISP_CLK_1
  _delay_us(ISP_CLK_DELAY);
  ISP_CLK_0
  _delay_us(ISP_CLK_DELAY);
  out = out >> 1;
  if (ISP_DAT_V)
    out = out | 0x8000;
  }
 return out;
}

unsigned int isp_read_8 (void)
{
unsigned char i;
unsigned int out;
out = 0;
ISP_DAT_D_I
//_delay_us(3*ISP_CLK_DELAY);
for (i=0;i<8;i++)
  {
  ISP_CLK_1
  _delay_us(ISP_CLK_DELAY);
  ISP_CLK_0
  _delay_us(ISP_CLK_DELAY);
  out = out >> 1;
  if (ISP_DAT_V)
    out = out | 0x80;
  }
 return out;
}

unsigned int isp_read_14s (void)
{
unsigned char i;
unsigned int out;
out = isp_read_16();
out = out &0x7FFE;
out = out >> 1;
return out;
}



void isp_send (unsigned int data, unsigned char n)
{
unsigned char i;
ISP_DAT_D_0
//_delay_us(3*ISP_CLK_DELAY);
for (i=0;i<n;i++)
  {
  if (data&0x01)
    {
    ISP_DAT_1
    }
  else
    {
    ISP_DAT_0
    }
  _delay_us(ISP_CLK_DELAY);
  ISP_CLK_1
//  _delay_us(ISP_CLK_DELAY);
  data = data >> 1;
  ISP_CLK_0
  ISP_DAT_0
//  _delay_us(ISP_CLK_DELAY);
  }
}


void isp_send_24_msb (unsigned long data)
{
unsigned char i;
ISP_DAT_D_0
//_delay_us(3*ISP_CLK_DELAY);
for (i=0;i<23;i++)
  {
  if (data&0x400000)
    {
    ISP_DAT_1
    }
  else
    {
    ISP_DAT_0
    }
  _delay_us(ISP_CLK_DELAY);
  ISP_CLK_1
 _delay_us(ISP_CLK_DELAY);
  data = data << 1;
  ISP_CLK_0
//  _delay_us(ISP_CLK_DELAY);
  }
  ISP_DAT_0
  _delay_us(ISP_CLK_DELAY);
  ISP_CLK_1
  _delay_us(ISP_CLK_DELAY);
  ISP_CLK_0
}

void isp_send_8_msb (unsigned char data)
{
unsigned char i;
ISP_DAT_D_0
//_delay_us(3*ISP_CLK_DELAY);
for (i=0;i<8;i++)
  {
  if (data&0x80)
    {
    ISP_DAT_1
    }
  else
    {
    ISP_DAT_0
    }
  _delay_us(ISP_CLK_DELAY);
  ISP_CLK_1
  _delay_us(ISP_CLK_DELAY);
  data = data << 1;
  ISP_CLK_0
  ISP_DAT_0
//  _delay_us(ISP_CLK_DELAY);
  }
}


unsigned int isp_read_8_msb (void)
{
unsigned char i;
unsigned int out;
out = 0;
ISP_DAT_D_I
//_delay_us(3*ISP_CLK_DELAY);
for (i=0;i<8;i++)
  {
  ISP_CLK_1
  _delay_us(ISP_CLK_DELAY);
  ISP_CLK_0
  _delay_us(ISP_CLK_DELAY);
  out = out << 1;
  if (ISP_DAT_V)
    out = out | 0x1;
  }
 return out;
}

unsigned int isp_read_16_msb (void)
{
unsigned char i;
unsigned int out;
out = 0;
ISP_DAT_D_I
//_delay_us(3*ISP_CLK_DELAY);
for (i=0;i<16;i++)
  {
  ISP_CLK_1
  _delay_us(ISP_CLK_DELAY);
  ISP_CLK_0
  _delay_us(ISP_CLK_DELAY);
  out = out << 1;
  if (ISP_DAT_V)
    out = out | 0x1;
  }
 return out;
}



unsigned char enter_progmode (void)
{
ISP_MCLR_0
_delay_us(300);
isp_send(0b01010000,8);
isp_send(0b01001000,8);
isp_send(0b01000011,8);
isp_send(0b01001101,8);

isp_send(0,1);

}

/**************************************************************************************************************************/

unsigned char p18_enter_progmode (void)
{
ISP_MCLR_0
_delay_us(300);
isp_send(0b10110010,8);
isp_send(0b11000010,8);
isp_send(0b00010010,8);
isp_send(0b00001010,8);
_delay_us(300);
ISP_MCLR_1
}


void p18_isp_mass_erase (void)
{
p18_set_tblptr(0x3C0005);
p18_send_cmd_payload(0x0C,0x0F0F);
p18_set_tblptr(0x3C0004);
p18_send_cmd_payload(0x0C,0x8F8F);
p18_send_cmd_payload(0,0x0000);
isp_send(0x00,4);
_delay_ms(20);
isp_send(0x00,16);
}

void p18fj_isp_mass_erase (void)
{
p18_set_tblptr(0x3C0005);
p18_send_cmd_payload(0x0C,0x0101);
p18_set_tblptr(0x3C0004);
p18_send_cmd_payload(0x0C,0x8080);
p18_send_cmd_payload(0,0x0000);
isp_send(0x00,4);
_delay_ms(600);
isp_send(0x00,16);
}


void p18fk_isp_mass_erase (unsigned char data1, unsigned char data2, unsigned char data3)
{
unsigned int tmp1, tmp2, tmp3;
tmp1 = data1;
tmp1 = (tmp1<<8)|data1;
tmp2 = data2;
tmp2 = (tmp2<<8)|data2;
tmp3 = data3;
tmp3 = (tmp3<<8)|data3;
p18_set_tblptr(0x3C0004);
p18_send_cmd_payload(0x0C,tmp3);
p18_set_tblptr(0x3C0005);
p18_send_cmd_payload(0x0C,tmp2);
p18_set_tblptr(0x3C0006);
p18_send_cmd_payload(0x0C,tmp1);
p18_send_cmd_payload(0x00,0);
isp_send(0x00,4);
_delay_ms(5);
isp_send(0x00,16);
}

void p18fk_isp_write_pgm (unsigned int * data, unsigned long addr, unsigned char n)
{
unsigned char i;
//_delay_us(3*ISP_CLK_DELAY);
p18_send_cmd_payload(0,0x8E7F);
p18_send_cmd_payload(0,0x9C7F);
p18_send_cmd_payload(0,0x847F);
p18_set_tblptr(addr);
for (i=0;i<n-1;i++)  
  p18_send_cmd_payload(0x0D,data[i]);  
p18_send_cmd_payload(0x0F,data[n-1]);  
p_18_modfied_nop(0);
}

void p18_isp_write_pgm (unsigned int * data, unsigned long addr, unsigned char n)
{
unsigned char i;
//_delay_us(3*ISP_CLK_DELAY);
p18_send_cmd_payload(0,0x8EA6);
p18_send_cmd_payload(0,0x9CA6);
p18_send_cmd_payload(0,0x84A6);
p18_set_tblptr(addr);
for (i=0;i<n-1;i++)  
  p18_send_cmd_payload(0x0D,data[i]);  
p18_send_cmd_payload(0x0F,data[n-1]);  
p_18_modfied_nop(1);
}

void p18_isp_write_cfg (unsigned char data1, unsigned char data2, unsigned long addr)
{
unsigned int i;
//_delay_us(3*ISP_CLK_DELAY);
p18_send_cmd_payload(0,0x8EA6);
p18_send_cmd_payload(0,0x8CA6);
p18_send_cmd_payload(0,0x84A6);
p18_set_tblptr(addr);
p18_send_cmd_payload(0x0F,data1);  
p_18_modfied_nop(1);
_delay_ms(5);
p18_set_tblptr(addr+1);
i = data2;
i = i << 8;
p18_send_cmd_payload(0x0F,i);  
p_18_modfied_nop(1);
_delay_ms(5);
}

void p18fk_isp_write_cfg (unsigned char data1, unsigned char data2, unsigned long addr)
{
unsigned int i;
//_delay_us(3*ISP_CLK_DELAY);
p18_send_cmd_payload(0,0x8E7F);
p18_send_cmd_payload(0,0x8C7F);
p18_set_tblptr(addr);
p18_send_cmd_payload(0x0F,data1);  
p_18_modfied_nop(1);
_delay_ms(5);
p18_set_tblptr(addr+1);
i = data2;
i = i << 8;
p18_send_cmd_payload(0x0F,i);  
p_18_modfied_nop(1);
_delay_ms(5);
}

void p_18_modfied_nop (unsigned char nop_long)
{
unsigned char i;
ISP_DAT_D_0
ISP_DAT_0
for (i=0;i<3;i++)
  {
  _delay_us(ISP_CLK_DELAY);
  ISP_CLK_1
  _delay_us(ISP_CLK_DELAY);
   ISP_CLK_0
  }
_delay_us(ISP_CLK_DELAY);
ISP_CLK_1
if (nop_long==1) _delay_ms(4);
_delay_ms(1);
ISP_CLK_0
_delay_us(ISP_CLK_DELAY);
isp_send(0x00,16);
}

void p_18_isp_read_pgm (unsigned int * data, unsigned long addr, unsigned char n)
{
unsigned char i;
unsigned int tmp1,tmp2;
//_delay_us(3*ISP_CLK_DELAY);
p18_set_tblptr(addr);
for (i=0;i<n;i++)  
  {
  tmp1 =  p18_read_pgm_byte();
  tmp2 =  p18_read_pgm_byte();
  tmp2 = tmp2<<8;
  data[i] = tmp1|tmp2;
  }
}


void p18_set_tblptr (unsigned long val)
{
  p18_send_cmd_payload(0,0x0E00|((val>>16)&0xFF));
  p18_send_cmd_payload(0,0x6EF8);
  p18_send_cmd_payload(0,0x0E00|((val>>8)&0xFF));
  p18_send_cmd_payload(0,0x6EF7);
  p18_send_cmd_payload(0,0x0E00|((val>>0)&0xFF));
  p18_send_cmd_payload(0,0x6EF6);
  }


unsigned char p18_read_pgm_byte (void)
{
  isp_send(0x09,4);
  isp_send(0x00,8);
  return isp_read_8();
  }

unsigned int p18_get_ID (void)
{
  unsigned int temp;

  p18_set_tblptr(0x3FFFFE);
  temp = p18_read_pgm_byte();
  temp = temp << 8;
  temp = temp | p18_read_pgm_byte();
  return temp;
  }

void p18_send_cmd_payload (unsigned char cmd, unsigned int payload)
{
  isp_send(cmd,4);
  isp_send(payload,16);
  _delay_us(30);
  }

unsigned int p18_get_cmd_payload (unsigned char cmd)
{
  isp_send(cmd,4);
  return isp_read_16();
  }


unsigned char exit_progmode (void)
{
ISP_MCLR_1
_delay_ms(30);
ISP_MCLR_0
_delay_ms(30);
ISP_MCLR_1
}

//***********************************************************************************//

unsigned char p16c_enter_progmode (void)
{
ISP_MCLR_0
_delay_us(300);
isp_send_8_msb(0x4d);
isp_send_8_msb(0x43);
isp_send_8_msb(0x48);
isp_send_8_msb(0x50);
_delay_us(300);
}

void p16c_set_pc (unsigned long pc)
{
  isp_send_8_msb(0x80);
  _delay_us(2);
  isp_send_24_msb(pc);

}

void p16c_bulk_erase (void)
{
  isp_send_8_msb(0x18);
  _delay_ms(100);
}

void p16c_load_nvm (unsigned int data, unsigned char inc)
{
  if (inc==0) isp_send_8_msb(0x00);
  else isp_send_8_msb(0x02);
  _delay_us(2);
  isp_send_24_msb(data);
  _delay_us(2);
  }

unsigned int p16c_read_data_nvm (unsigned char inc)
{
  unsigned int retval;
  unsigned char tmp;
  if (inc==0) isp_send_8_msb(0xFC);
  else isp_send_8_msb(0xFE);
  _delay_us(2);
  tmp = isp_read_8_msb();
  retval = isp_read_16_msb();
  retval = retval >> 1;
  if (tmp&0x01) retval = retval | 0x8000;
  return retval;
  }

void p16c_begin_prog (unsigned char cfg_bit)
{
  isp_send_8_msb(0xE0);
  _delay_ms(3);  
  if (cfg_bit!=0) _delay_ms(3); 
  }

unsigned int p16c_get_ID (void)
{
  p16c_set_pc(0x8006);
  return p16c_read_data_nvm(1);
  }
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

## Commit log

2015-11-24 hw/sw revision 1, somehow dirty job
    [approg.brd, approg.sch]
2015-12-01 gerber data
    gerber data
    [approg.GBL, approg.GBO, approg.GBP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]
2015-12-02 files cleanup
    files cleanup
    [approg.brd, approg.sch]
2015-12-23 BOM update
    BOM update
    [BOM.csv, approg.brd, approg.sch]
2016-07-26 PIC16 and PIC18 united
    and a lot of bugs fixed, PIC12F1xxx support
    [pp.ino]
2016-07-29 New devices supproted
2016-07-30 new devices, bugfixes
2016-08-05 device support update
2016-08-16 device support
    new PIC16F1, new PIC18FJ family
2016-09-05 version 0.9
    a lot of devices added, bugfixes
2016-09-09 ver 0.92
    massive rework of MCU selection, added MCU database, 67 new devices
    added
    [pp.ino]
2016-09-14 ver 0.94
    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
    [pp.ino]
2020-04-23 Fixed PIC16F1619 device ID typo and confirmed working
2021-04-22 Corrected inverted 18f47q10 / 18f27q10 signatures
    They were swapped see page 38 of https://ww1.microchip.com/downloads/en/DeviceDoc/PIC18F27-47Q10-Data-Sheet-40002043E.pdf

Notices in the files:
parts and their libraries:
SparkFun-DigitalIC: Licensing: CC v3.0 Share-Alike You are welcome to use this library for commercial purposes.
